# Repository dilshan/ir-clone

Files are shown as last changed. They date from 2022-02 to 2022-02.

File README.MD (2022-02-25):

IR Remote Control Clone Utility
===============================

IR Clone is an open-source infrared remote control signal analysis and generating tool. This utility can clone IR signals, examine the IR remote control signals, and modify or create new IR signals. 

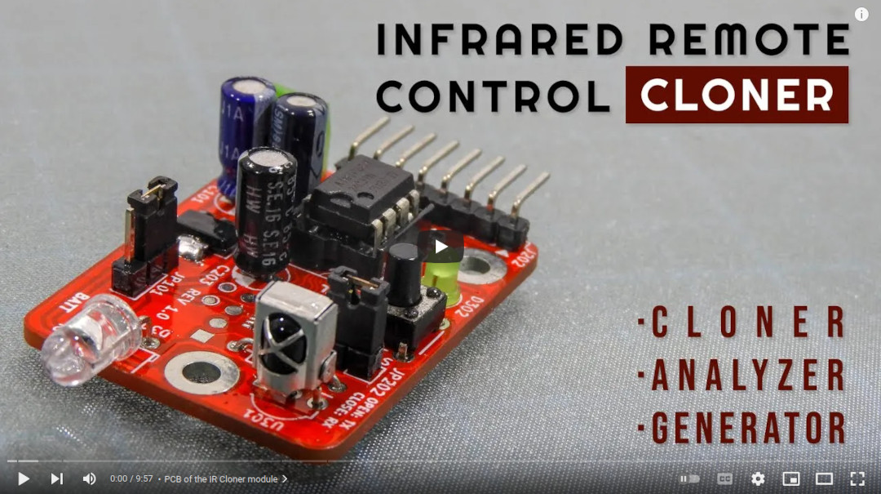
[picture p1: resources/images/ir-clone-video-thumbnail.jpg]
IR Clone build video (https://youtu.be/PBt0_21yzKo)


This project consists of both hardware and software utilities. The hardware module contains an 8-bit MCU, 32Kbit EEPROM, IR receiver, and transmitter.

The software application provides options to decode captured data and generate new IR signals.

IR Clone is an [OSHW certified](https://certification.oshwa.org/lk000011.html) open-source project. All the schematics, PCB design files, firmware source codes, and application source codes are available in this repository.

The complete [documentation](https://github.com/dilshan/ir-clone/wiki) of this project is available in the [wiki](https://github.com/dilshan/ir-clone/wiki) section of this repository. The PCB Gerber files and compiled binaries are also available in the [release](https://github.com/dilshan/ir-clone/releases) section of this repository.

All the content of this project are distributed under the terms of the following license:

- Hardware License: [CERN-OHL-W 2.0](https://ohwr.org/cern_ohl_w_v2.txt)
- Software License: [MIT](https://github.com/dilshan/ir-clone/blob/main/LICENSE)
- [Documentation](https://github.com/dilshan/ir-clone/wiki) License: [CC BY 4.0](https://creativecommons.org/licenses/by/4.0/)

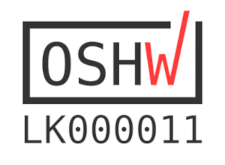
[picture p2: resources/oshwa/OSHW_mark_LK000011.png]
OSHW-LK000011 (https://certification.oshwa.org/lk000011.html)


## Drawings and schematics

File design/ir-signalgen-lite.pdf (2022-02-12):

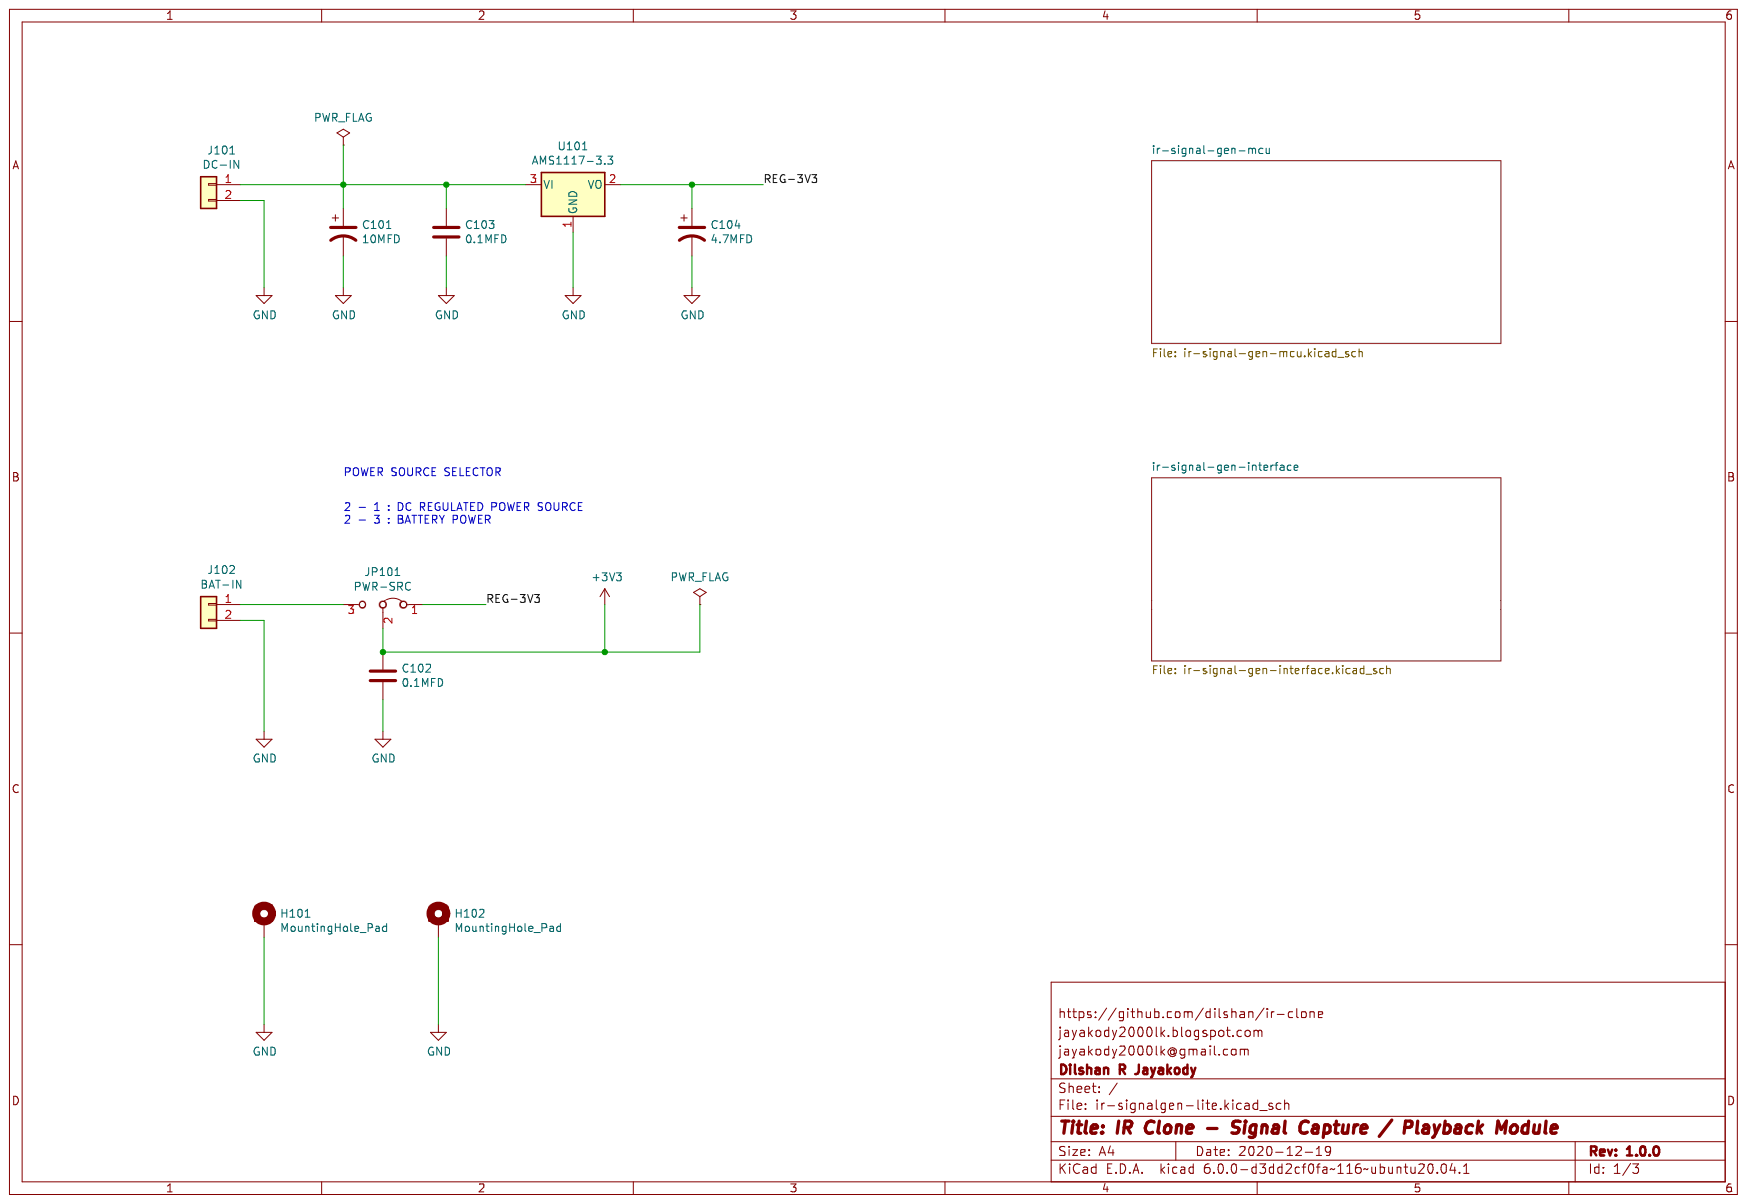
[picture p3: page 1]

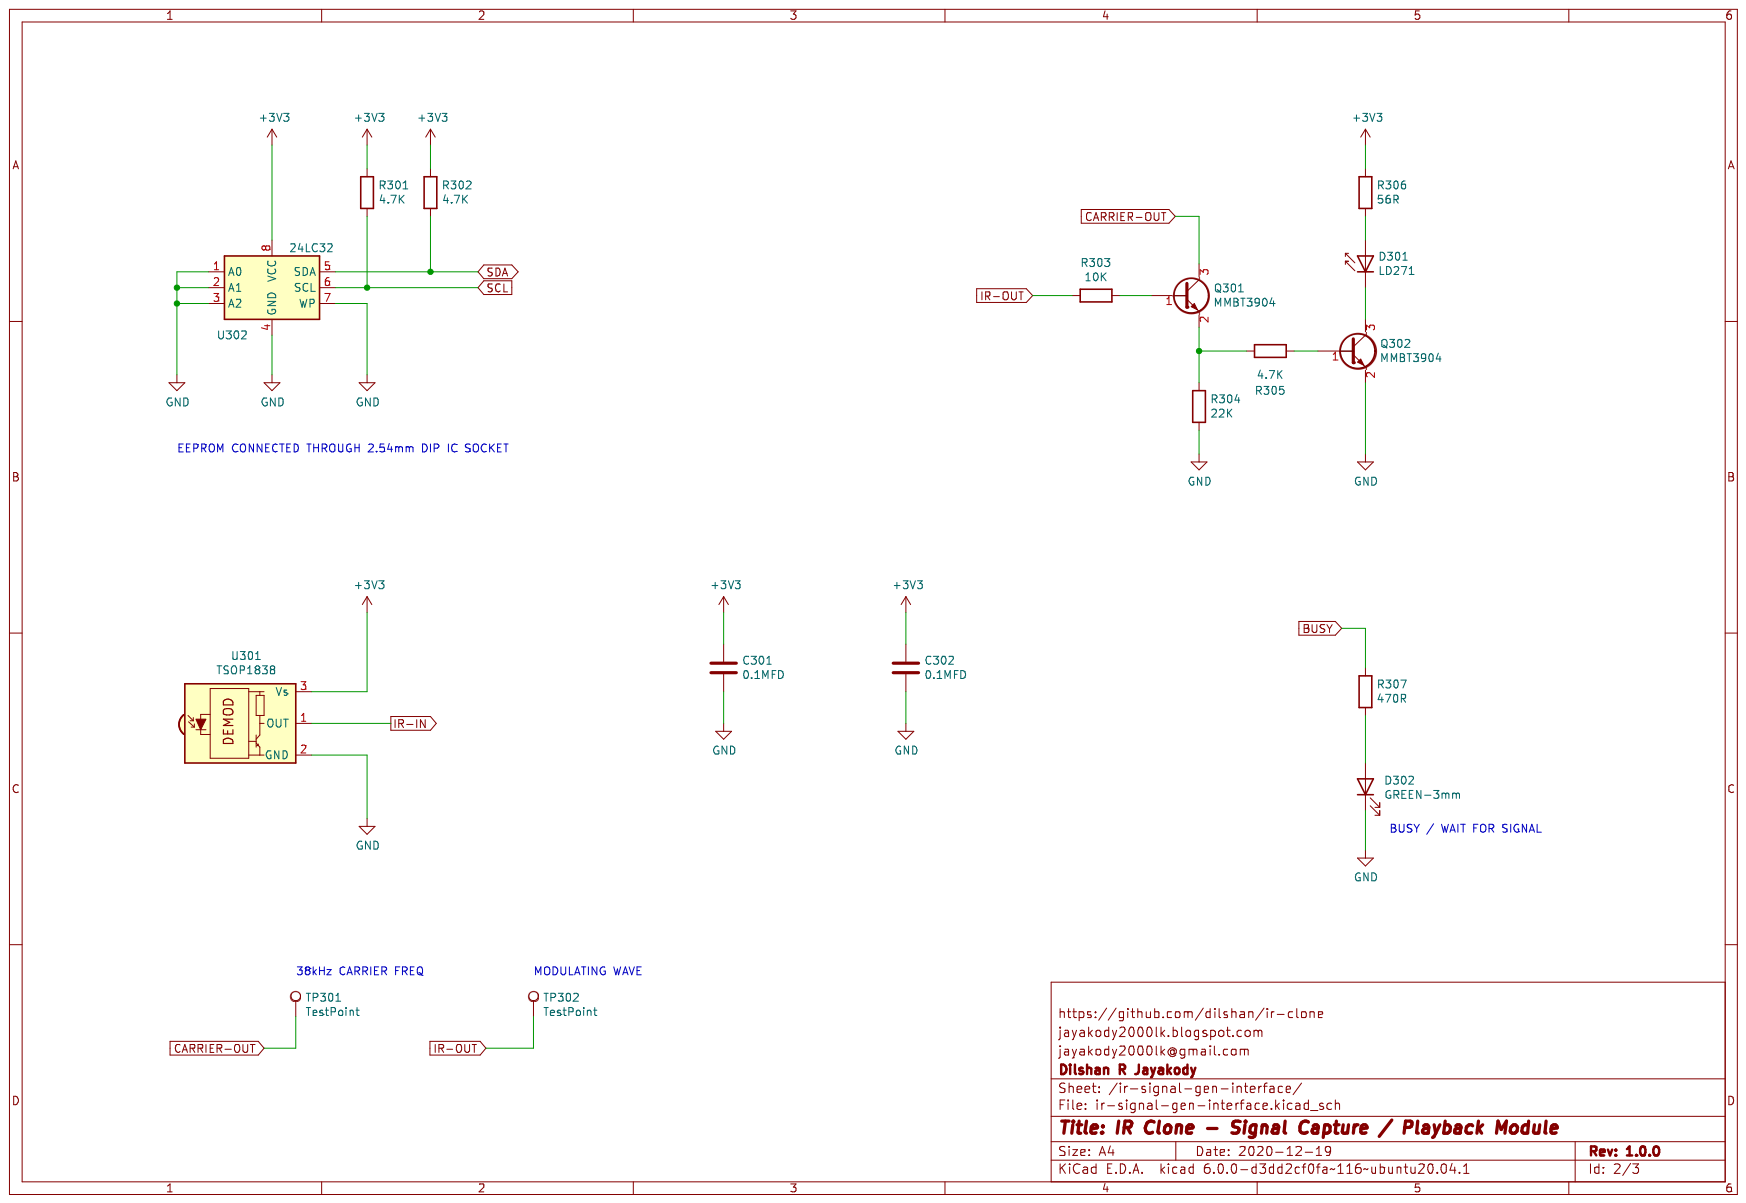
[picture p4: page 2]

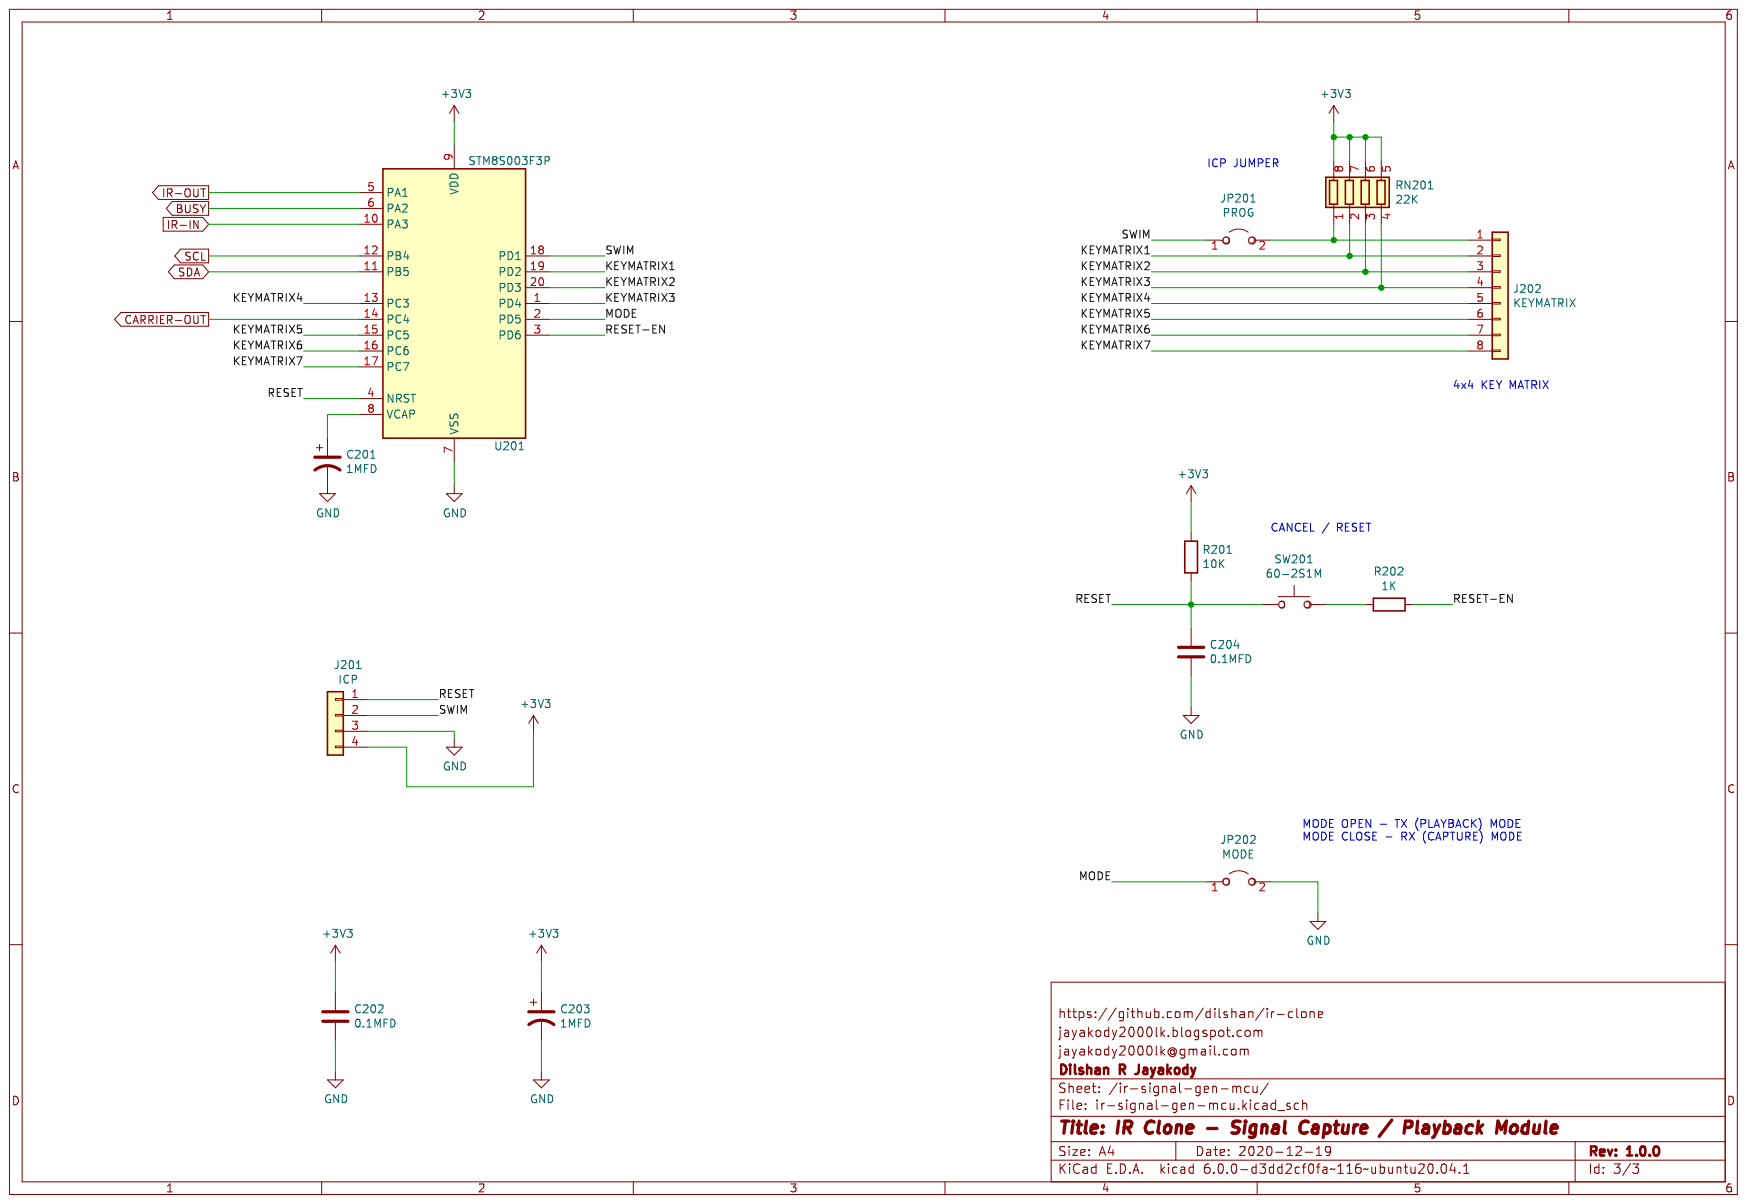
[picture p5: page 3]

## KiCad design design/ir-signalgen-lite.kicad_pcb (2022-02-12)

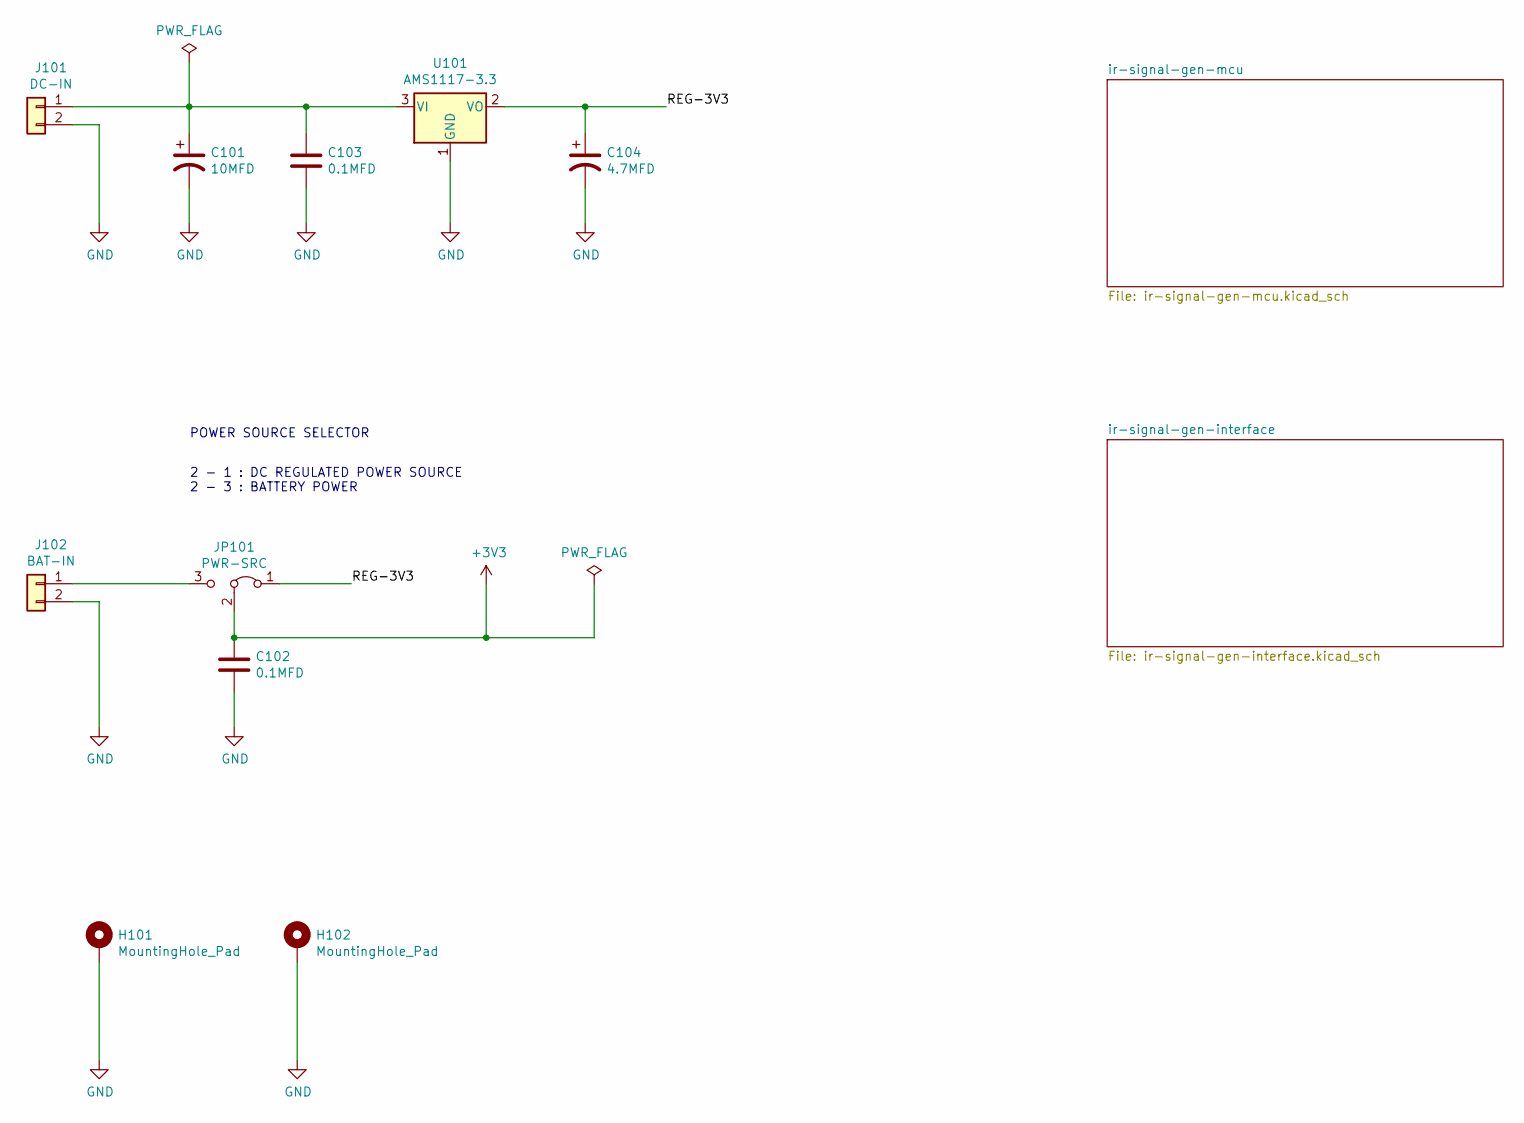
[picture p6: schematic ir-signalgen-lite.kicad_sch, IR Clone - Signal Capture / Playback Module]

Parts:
C101: 10MFD; CP_Radial_D5.0mm_P2.50mm
C102, C103: 0.1MFD; C_0805_2012Metric_Pad1.18x1.45mm_HandSolder
C104: 4.7MFD; CP_Radial_D5.0mm_P2.50mm
H101, H102: MountingHole_Pad; MountingHole_3.2mm_M3_Pad
J101: DC-IN; PhoenixContact_MCV_1,5_2-G-3.5_1x02_P3.50mm_Vertical
J102: BAT-IN; PinHeader_1x02_P2.54mm_Vertical
JP101: PWR-SRC; PinHeader_1x03_P2.54mm_Vertical
U101: AMS1117-3.3; SOT-223-3_TabPin2

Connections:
+3V3: C102.1, JP101.2 (C); also elsewhere on the board
/REG-3V3: C104.1, JP101.1 (A), U101.2 (VO)
GND: C101.2, C102.2, C103.2, C104.2, H101.1, H102.1, J101.2, J102.2, U101.1 (GND); also elsewhere on the board
unnamed: C101.1, C103.1, J101.1, U101.3 (VI)
unnamed: J102.1, JP101.3 (B)

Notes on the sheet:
POWER SOURCE SELECTOR
2 - 1 : DC REGULATED POWER SOURCE 2 - 3 : BATTERY POWER

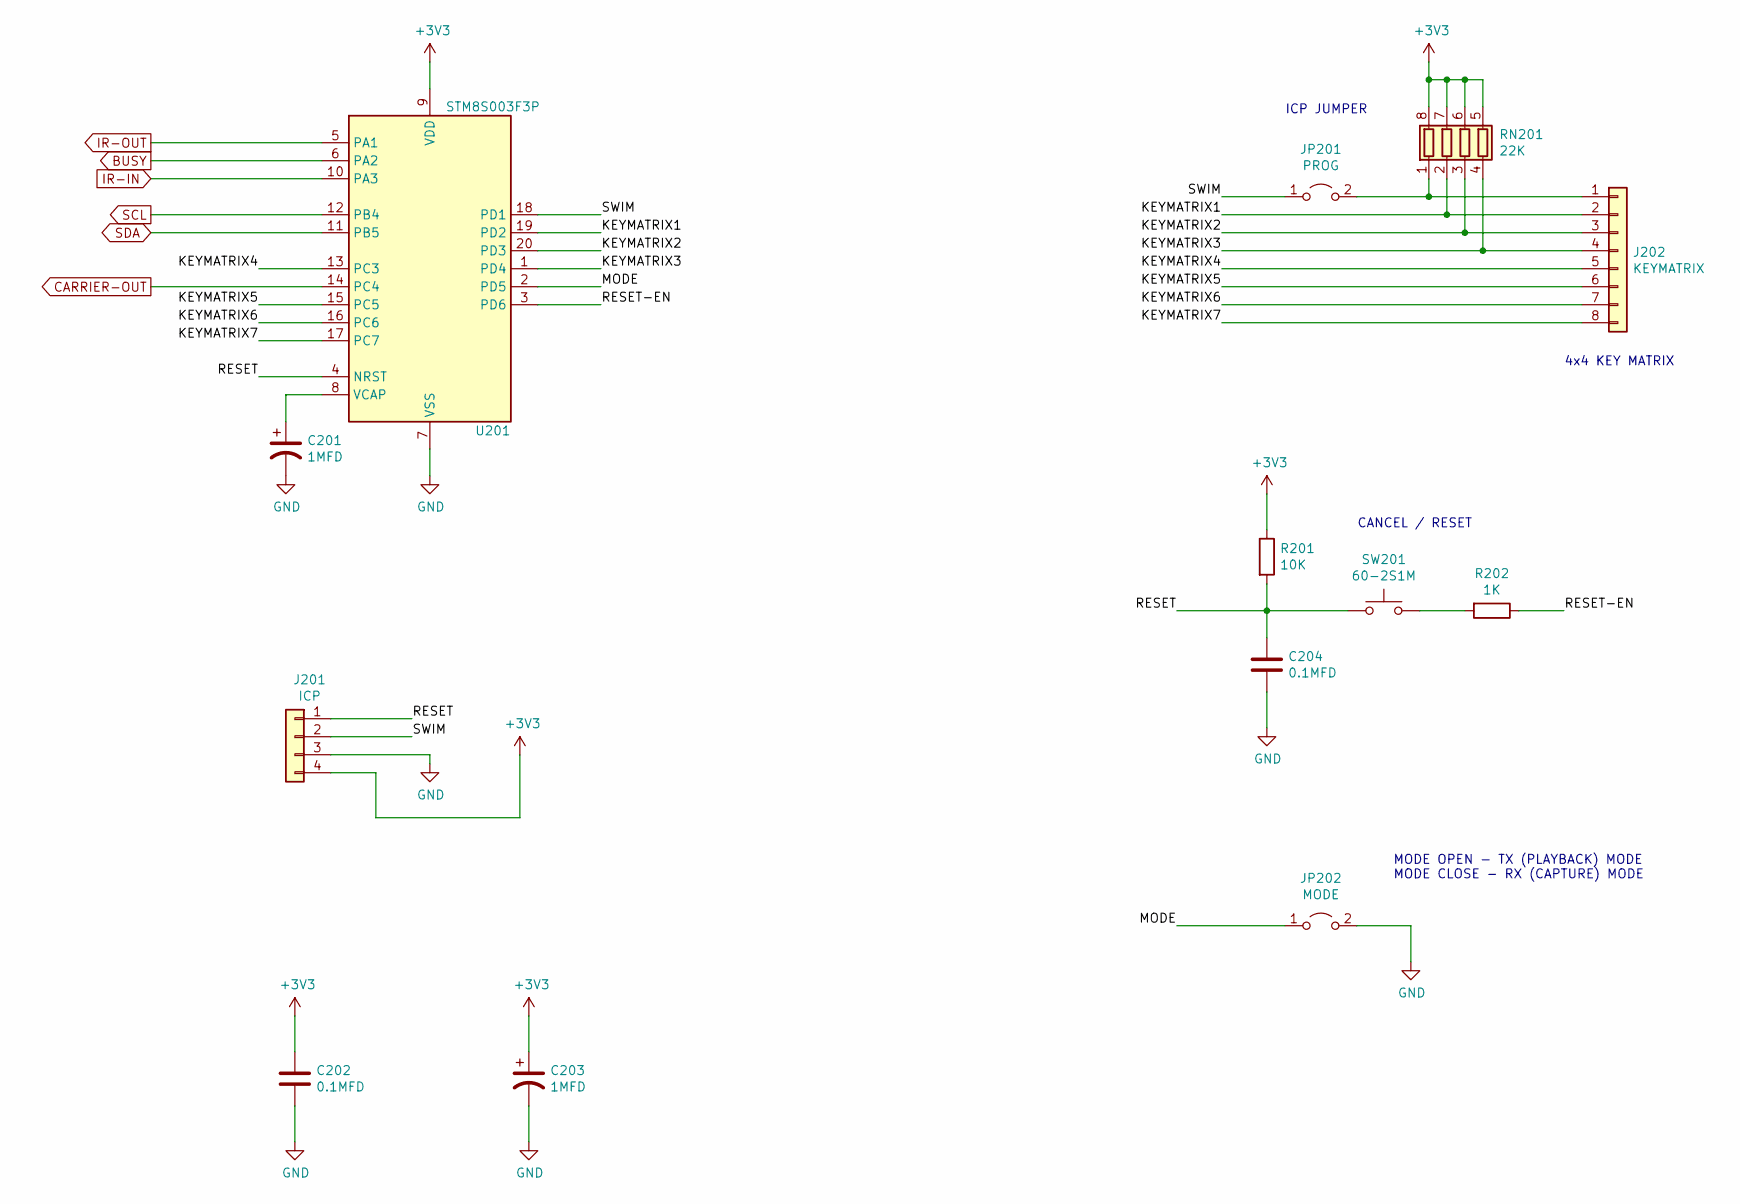
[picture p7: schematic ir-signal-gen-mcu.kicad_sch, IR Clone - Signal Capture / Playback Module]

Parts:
C201: 1MFD; C_0805_2012Metric_Pad1.18x1.45mm_HandSolder
C202, C204: 0.1MFD; C_0805_2012Metric_Pad1.18x1.45mm_HandSolder
C203: 1MFD; CP_Radial_D5.0mm_P2.50mm
J201: ICP; pogo-2.54mmx4
J202: KEYMATRIX; PinHeader_1x08_P2.54mm_Vertical
JP201: PROG; SolderJumper-2_P1.3mm_Bridged_Pad1.0x1.5mm
JP202: MODE; PinHeader_1x02_P2.54mm_Vertical
R201: 10K; R_0805_2012Metric_Pad1.20x1.40mm_HandSolder
R202: 1K; R_0805_2012Metric_Pad1.20x1.40mm_HandSolder
RN201: 22K; R_Array_Convex_4x0603
SW201: 60-2S1M; SW_PUSH_6mm
U201: STM8S003F3P; TSSOP-20_4.4x6.5mm_P0.65mm

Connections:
+3V3: C202.1, C203.1, J201.4, R201.1, RN201.5 (R4.2), RN201.6 (R3.2), RN201.7 (R2.2), RN201.8 (R1.2), U201.9 (VDD); also elsewhere on the board
/ir-signal-gen-mcu/KEYMATRIX1: J202.2, RN201.2 (R2.1), U201.19 (PD2)
/ir-signal-gen-mcu/KEYMATRIX2: J202.3, RN201.3 (R3.1), U201.20 (PD3)
/ir-signal-gen-mcu/KEYMATRIX3: J202.4, RN201.4 (R4.1), U201.1 (PD4)
/ir-signal-gen-mcu/KEYMATRIX4: J202.5, U201.13 (PC3)
/ir-signal-gen-mcu/KEYMATRIX5: J202.6, U201.15 (PC5)
/ir-signal-gen-mcu/KEYMATRIX6: J202.7, U201.16 (PC6)
/ir-signal-gen-mcu/KEYMATRIX7: J202.8, U201.17 (PC7)
/ir-signal-gen-mcu/MODE: JP202.1 (A), U201.2 (PD5)
/ir-signal-gen-mcu/RESET: C204.1, J201.1, R201.2, SW201.1, U201.4 (NRST)
/ir-signal-gen-mcu/RESET-EN: R202.1, U201.3 (PD6)
/ir-signal-gen-mcu/SWIM: J201.2, JP201.1 (A), U201.18 (PD1)
BUSY: U201.6 (PA2); also elsewhere on the board
CARRIER-OUT: U201.14 (PC4); also elsewhere on the board
GND: C201.2, C202.2, C203.2, C204.2, J201.3, JP202.2 (B), U201.7 (VSS); also elsewhere on the board
IR-IN: U201.10 (PA3); also elsewhere on the board
IR-OUT: U201.5 (PA1); also elsewhere on the board
unnamed: C201.1, U201.8 (VCAP)
unnamed: J202.1, JP201.2 (B), RN201.1 (R1.1)
unnamed: R202.2, SW201.2
SCL: U201.12 (PB4); also elsewhere on the board
SDA: U201.11 (PB5); also elsewhere on the board

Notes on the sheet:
ICP JUMPER
CANCEL / RESET
MODE OPEN - TX (PLAYBACK) MODE MODE CLOSE - RX (CAPTURE) MODE
4x4 KEY MATRIX

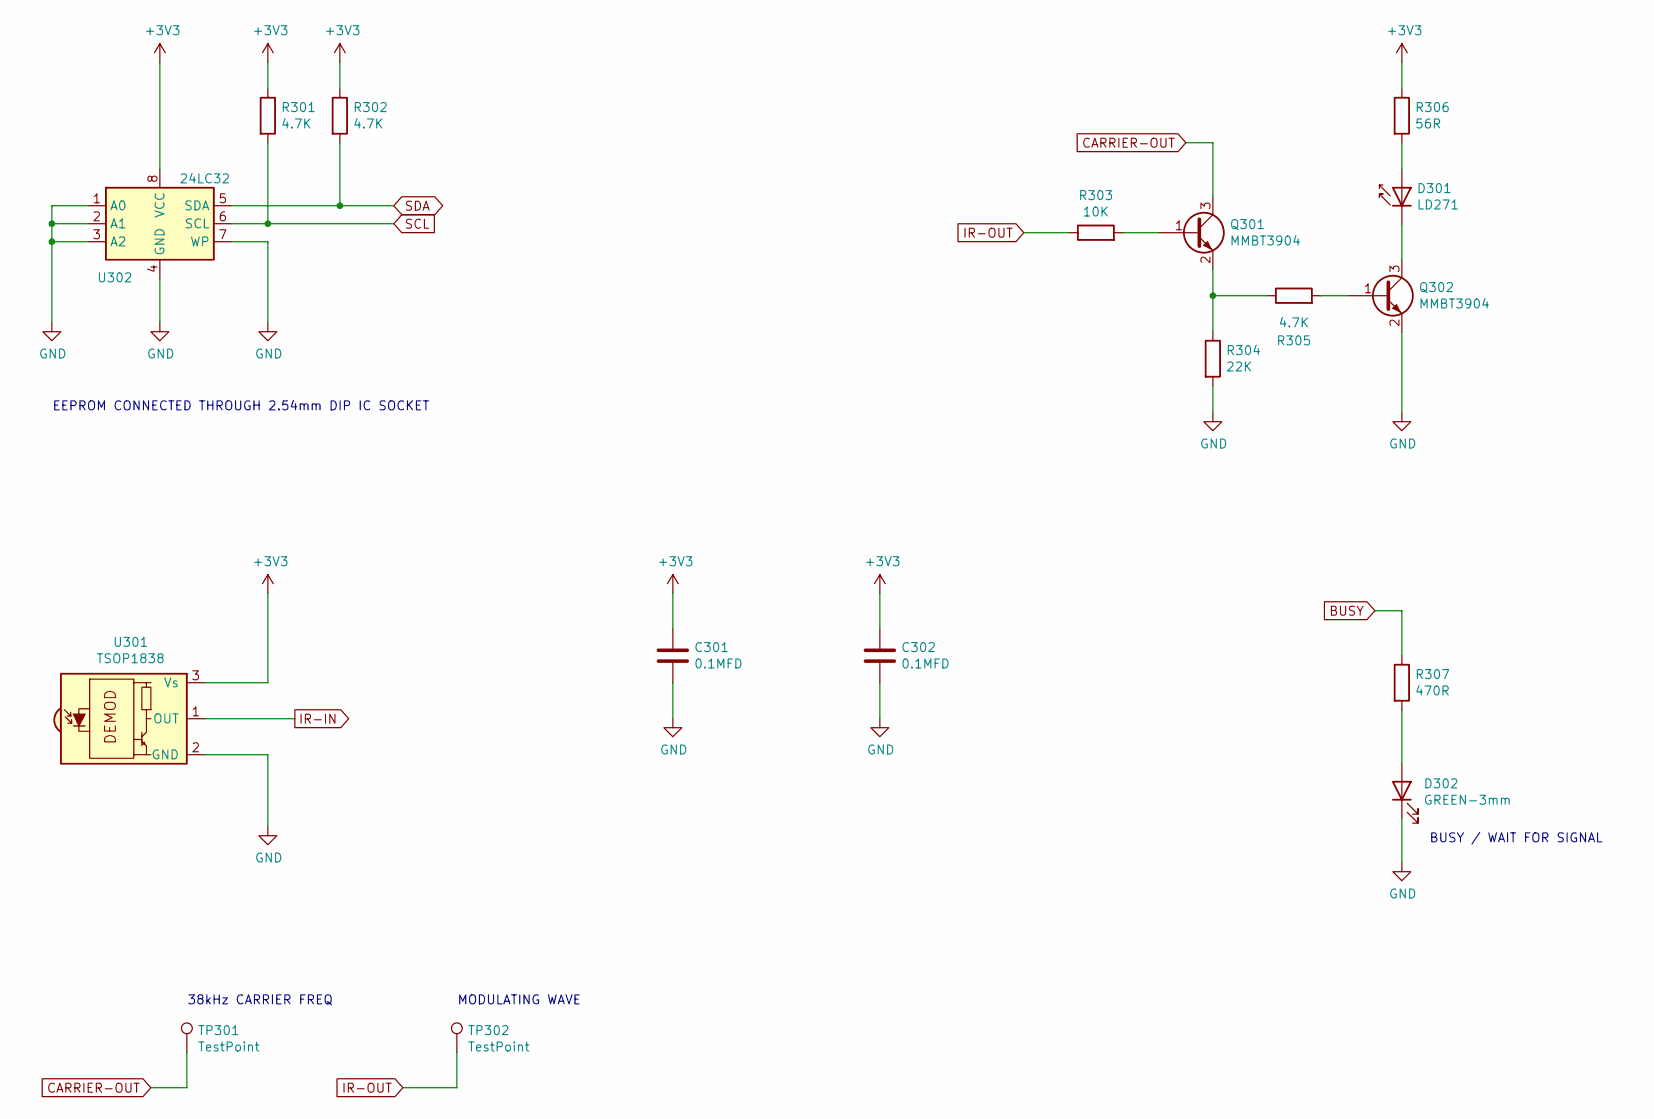
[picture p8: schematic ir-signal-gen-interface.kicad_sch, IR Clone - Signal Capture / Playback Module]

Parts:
C301, C302: 0.1MFD; C_0805_2012Metric_Pad1.18x1.45mm_HandSolder
D301: LD271; LED_D5.0mm_Horizontal_O1.27mm_Z3.0mm
D302: GREEN-3mm; LED_D3.0mm
Q301, Q302: MMBT3904; SOT-23
R301, R302, R305: 4.7K; R_0805_2012Metric_Pad1.20x1.40mm_HandSolder
R303: 10K; R_0805_2012Metric_Pad1.20x1.40mm_HandSolder
R304: 22K; R_0805_2012Metric_Pad1.20x1.40mm_HandSolder
R306: 56R; R_Axial_DIN0207_L6.3mm_D2.5mm_P10.16mm_Horizontal
R307: 470R; R_0805_2012Metric_Pad1.20x1.40mm_HandSolder
TP301, TP302: TestPoint; TestPoint_Pad_D1.0mm
U301: TSOP1838; Vishay_MOLD-3Pin
U302: 24LC32; DIP-8_W7.62mm_Socket_LongPads

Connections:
+3V3: C301.1, C302.1, R301.1, R302.1, R306.1, U301.3 (Vs), U302.8 (VCC); also elsewhere on the board
BUSY: R307.1; also elsewhere on the board
CARRIER-OUT: Q301.3 (C), TP301.1; also elsewhere on the board
GND: C301.2, C302.2, D302.1 (K), Q302.2 (E), R304.2, U301.2 (GND), U302.1 (A0), U302.2 (A1), U302.3 (A2), U302.4 (GND), U302.7 (WP); also elsewhere on the board
IR-IN: U301.1 (OUT); also elsewhere on the board
IR-OUT: R303.1, TP302.1; also elsewhere on the board
unnamed: D301.1 (K), Q302.3 (C)
unnamed: D301.2 (A), R306.2
unnamed: D302.2 (A), R307.2
unnamed: Q301.1 (B), R303.2
unnamed: Q301.2 (E), R304.1, R305.1
unnamed: Q302.1 (B), R305.2
SCL: R301.2, U302.6 (SCL); also elsewhere on the board
SDA: R302.2, U302.5 (SDA); also elsewhere on the board

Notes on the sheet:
MODULATING WAVE
38kHz CARRIER FREQ
BUSY / WAIT FOR SIGNAL
EEPROM CONNECTED THROUGH 2.54mm DIP IC SOCKET

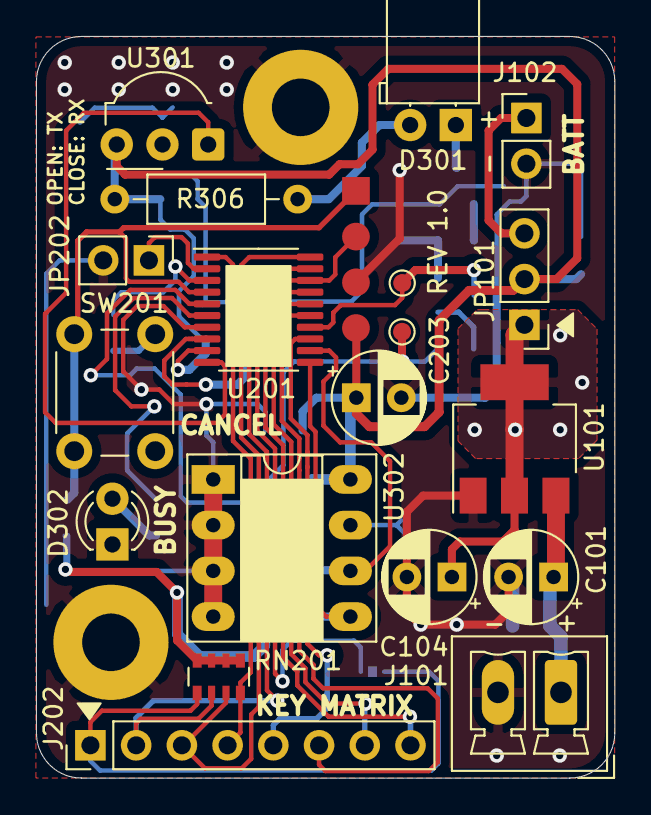
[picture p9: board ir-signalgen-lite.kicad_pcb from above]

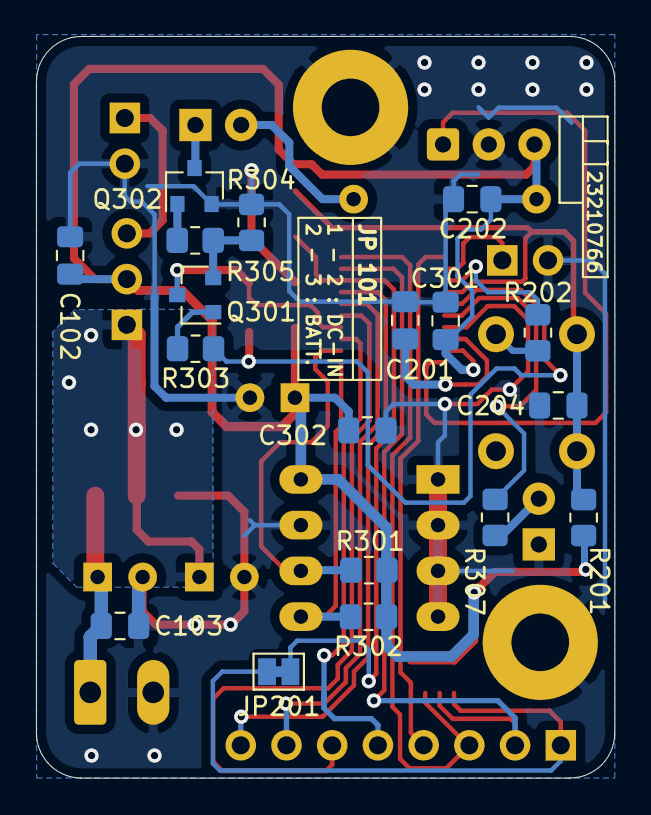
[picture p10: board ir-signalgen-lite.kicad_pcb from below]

Board: 2 copper layers, 32.1 x 41.2 mm, 40 parts (18 on the bottom side), 31 nets.

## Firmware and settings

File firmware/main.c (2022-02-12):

//----------------------------------------------------------------------------------
// IR Remote Cloner firmware for STM8S003F3P6.
// Main source file.
//
// Copyright (c) 2022 Dilshan R Jayakody
//
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
// Last updated: Dilshan Jayakody [11th Dec 2020]
//
// Update log:
// [11/12/2020] - Initial version - Dilshan Jayakody.
//----------------------------------------------------------------------------------

#include "main.h"

#include "include/stm8.h"
#include "include/stm8-util.h"
#include "24c-eeprom.h"

unsigned short captureBuffer[CAPTURE_BUFFER_SIZE];
volatile unsigned short timeCounter;
unsigned char bufferPos, bufferSize;
unsigned char inMemoryBufferID;
unsigned char sleepCounter;

void PortD_Trigger() __interrupt(PORTD_IRQ)
{
    // Device wake-up interrupt.
    sleepCounter = 0;
}

void TIM2_update() __interrupt(TIMER2_TRIGGER_IRQ)
{   
    sleepCounter++;
    
    // Clear timer 2 interrupt flag.
    TIM2_SR1 &= ~TIM2_SR1_UIF;
}

void main()
{
    const unsigned char scanData[4] = {0xE0, 0xC8, 0xA8, 0x68};
    unsigned char scanPos;
    unsigned char scanRow, scanCol;
    
    // Initialize the system registers and peripherals.
    cli(); 
    initSystem();

    initExtEEPROM();

    // Initialize global variables.
    timeCounter = 0;
    scanRow = 0;
    scanCol = 0;
    inMemoryBufferID = 0xFF;
    sleepCounter = 0;

    // Enable interrupts.
    sei();

    // Main service loop.
    while(1)
    {        
        // Check for device wake-up from sleep mode.
        if(PD_CR2 != 0x00)
        {
            // Disable port D interrupts and shutdown Port C pull-down configuration.            
            PD_CR2 = 0x00;
            PC_ODR = 0xE8;
            PD_ODR = 0x40;
        }

        // Check idle timeout to enter device into sleep mode.
        if(sleepCounter > IDLE_TIMEOUT)
        {            
            // Enter device into sleep mode.
            PD_CR2 = 0x1E;
            PD_ODR = 0x00;

            // Set Port C to pull-down configuration to detect user key press (for wake-up).
            PC_ODR &= 0x17;
            sleepCounter = 0;

            halt();
        }
        
        scanPos = 0;
        scanRow = 0;
        scanCol = 0;

        // Start checking key-matrix for any key presses.
        while(scanPos < 4)
        {
            PC_ODR = scanData[scanPos];            
            if((PD_IDR & 0x1E) != 0x1E)
            {
                // Key press found, detect row and column of the pressed-key.
                sleepCounter = 0;
                scanRow = scanPos + 1;
                scanCol = ((~PD_IDR) & 0x1E) >> 1;
                break;
            }
            
            scanPos++;
        }

        // Reset (shutdown) keyboard scanning signals.
        PC_ODR = 0xE8;

        if((scanCol > 0) && (scanRow > 0))
        {
            // Key press is released, execute the action related to the key.
            scanPos = decodeKeyMatrix(&scanRow, &scanCol);

            if(scanPos < 16)
            {                
                // Disable interrupts and enable reset control.
                cli();
                PD_ODR = 0x00;

                // Select capture or transmit based on the mode jumper.
                if((PD_IDR & 0x20))
                {
                    // Transmit mode.
                    startTransmit(scanPos);
                }
                else
                {
                    // Capture mode.                    
                    startCapture(scanPos);
                } 

                // Enable interrupts and disable reset control.
                sleepCounter = 0;

                sei();   
                PD_ODR = 0x40;
            }        
        }

        delay_ms(1);
    }
}

unsigned char decodeKeyMatrix(unsigned char *row, unsigned char *col)
{   
    unsigned char retKey;
    
    // Decode row value.
    switch(*row)
    {
        case 1:
            retKey = 0;
            break;
        case 2:
            retKey = 4;
            break;
        case 3:
            retKey = 8;
            break;
        case 4:
            retKey = 12;
            break;
        default:
            // Unknown row value.
            return 0xFF;
    }

    // Decode column value to get the final key-pressed value.
    switch (*col)
    {
        case 1:
            return retKey + 0;
        case 2:
            return retKey + 1;
        case 4:
            return retKey + 2;
        case 8:
            return retKey + 3;
        default:
            // Unknown column value.
            return 0xFF;
    }
}

void initSystem()
{
    // Switch high speed internal clock prescaler (HSIDIV) to divide by 0 mode (16MHz).
    CLK_ECKR = 0x00;    
    CLK_CKDIVR = 0x00;
    CLK_PCKENR1 = 0xFF;
    CLK_PCKENR2 = 0xFF;
    CLK_CCOR = 0x00;

    // Select high speed internal clock (HSI) as master clock. 
    CLK_SWR = 0xE1;
    
    // Switching to new clock configuration.
    CLK_SWCR = 0x00;
    CLK_SWCR |= 0x02;

    // Waiting for switching to new clock configuration.
    while(CLK_SWCR & 0x01);

    // PA1[OUT] : IR LED drive.
    // PA2[OUT] : Capture / Busy status LED.
    // PA3[IN]  : TSSOP1838 IR photo module input.
    PA_DDR = 0xF7;
    PA_CR1 = 0xFF;
    PA_CR2 = 0x00;
    PA_ODR = 0x00;

    // PD1..PD4 [IN] : Keyboard input.
    // PD5[IN]  : Capture / Transmit mode selector.
    // PD6[OUT] : Reset control pin.
    PD_DDR = 0xC1;
    PD_CR1 = 0x60;
    PD_CR2 = 0x00;
    PD_ODR = 0x40;

    // PC3, PC4..PC7 [OUT] : Keyboard scan data.
    PC_DDR = 0xE8;
    PC_CR1 = 0xE8;
    PC_CR2 = 0x00;
    PC_ODR = 0xE8;

    // Setup Timer 1 to generate 38kHz carrier waveform on TIM1_CH4.
    TIM1_ARRH = 0x00;
    TIM1_ARRL = 0x33;

    TIM1_PSCRH = 0;
    TIM1_PSCRL = 0x07;

    // Enable PWM mode 2 on Timer 1.
    TIM1_CCMR4 |= 0x70;

    // Set PWM output enable on Timer 1 channel 4 (TIM1_CH4).
    TIM1_CCER2 |= 0x10;

    // Based on TIM1_ARR set duty cycle to 50%.
    TIM1_CCR4H = 0x00;
    TIM1_CCR4L = 0x1A;

    // Enable main output.
    TIM1_BKR = 0x80; 

    // Turn off carrier waveform output.
    TIM1_CR1 = 0x00;  

    // Set timer 2 prescaler to 256.
    TIM2_PSCR = 8;

    // Set ARRH to get 1 second interrupt.
    TIM2_ARRH = 0xF4;
    TIM2_ARRL = 0x24; 

    // Enable timer 2 interrupt.
    TIM2_IER |= TIM2_IER_UIE;
    TIM2_CR1 |= TIM2_CR1_CEN;

    // Configure Port D interrupts to trigger on both rising and falling edges. 
    EXTI_CR1 |= 0xC0;
}

void startTransmit(unsigned char buttonID)
{
    unsigned short eepromAddr = buttonID * CAPTURE_BUFFER_SIZE * 2;
    unsigned char tempPos;

    // Activate busy LED.
    PA_ODR |= 0x04;

    // Load button data from the EEPROM, only if it is not available in the memory.
    if(inMemoryBufferID != buttonID)
    {
        // Clear data buffer.
        for(tempPos = 0; tempPos < CAPTURE_BUFFER_SIZE; tempPos++)
        {
            captureBuffer[tempPos] = 0;
        }
        
        // Get the length of the data buffer.
        bufferSize = readExtEEPROM(eepromAddr++);
        bufferPos = 0;
        delay_ms(5);

        // Load IR transmit data into buffer.
        if((bufferSize > 0) && (bufferSize < CAPTURE_BUFFER_SIZE))
        {
            while(bufferPos < bufferSize)
            {
                captureBuffer[bufferPos] = readExtEEPROM(eepromAddr++);
                captureBuffer[bufferPos] = captureBuffer[bufferPos] << 8;
                delay_ms(4);
                captureBuffer[bufferPos] |= readExtEEPROM(eepromAddr++);
                delay_ms(5);

                bufferPos++;
            }
        }
        else
        {
            // Invalid buffer size or corrupted EEPROM data.
            bufferPos = 0;
            PA_ODR &= 0xF9;

            return;
        }
    }

    // Activate carrier wave osciliator.
    TIM1_CR1 = 0x01;
    delay_ms(3);

    // Reset counter and set waveform output to low [0] level.
    bufferPos = 0;
    PA_ODR &= 0xFD;

    while(bufferPos < bufferSize)
    {
        // Get length of the next wavrform.
        timeCounter =  captureBuffer[bufferPos];
        if(timeCounter > 0)
        {
            // Toggle output waveform.
            PA_ODR ^= 0x02;

            // Consume length of the waveform.
            while(timeCounter > 0)
            {
                delay_cycle(TRANSMIT_DELAY);
                timeCounter--;
            }   
        }
        
        // Go to next waveform record.
        bufferPos++;
    }

    // Shutdown waveform output and carrier wave osciliator.
    PA_ODR &= 0xFD;
    TIM1_CR1 = 0x00;

    // Turn off busy indicator.
    PA_ODR &= 0xFB;

    // Set ID belongs to the current memory buffer.
    inMemoryBufferID = buttonID;
}

void startCapture(unsigned char buttonID)
{    
    unsigned char temp, bufPos;
    unsigned short eepromAddr = buttonID * CAPTURE_BUFFER_SIZE * 2;
    
    // Initialize variables used for capturing.
    timeCounter = 0;
    bufferPos = 0;
    inMemoryBufferID = 0xFF;

    // Clear data buffer.
    for(temp = 0; temp < CAPTURE_BUFFER_SIZE; temp++)
    {
        captureBuffer[temp] = 0;
    }

    // Activate capture LED.
    PA_ODR |= 0x04;
    temp = 0x08;

    // Waiting for IR signal to start the capture.
    while(PA_IDR & 0x08)
    {
        nop();
    }

    // Start capture loop.
    do
    {        
        if((PA_IDR & 0x08) ^ temp)
        {
            // Signal state change detected. Capture counter value and reset the counter.
            captureBuffer[bufferPos] = timeCounter;
            bufferPos++;
            timeCounter = 0;
            temp = (PA_IDR & 0x08);
        }
        
        // Wait for 10us delay.
        delay_cycle(CAPTURE_DELAY);
        timeCounter++;
    }
    while((timeCounter <= TIMEOUT_LIMIT) && (bufferPos < CAPTURE_BUFFER_SIZE));

    if(bufferPos > 0)
    {        
        // Write captured data into EEPROM.
        writeExtEEPROM(eepromAddr++, bufferPos);
        delay_ms(5);
        for(bufPos = 0; bufPos < bufferPos; bufPos++)
        {
            // Write captured time limits into the EEPROM.
            writeExtEEPROM(eepromAddr++, ((captureBuffer[bufPos] >> 8) & 0xFF));
            delay_ms(5);
            writeExtEEPROM(eepromAddr++, (captureBuffer[bufPos] & 0xFF));
            delay_ms(5);
        }
    }

    // Turn off capture indicator.
    PA_ODR &= 0xFB;
}

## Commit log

2022-02-12 Add initial version of schematic and PCB design files.
    [ir-signal-gen-interface.kicad_sch, ir-signal-gen-mcu.kicad_sch, ir-signalgen-lite.kicad_pcb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]
2022-02-16 Add Fritzing design files and test setup schematic.
    [ir-clone-test-setup.fzz]
2022-02-16 Update test setup with description.
    [ir-clone-test-setup.fzz]
2022-02-16 Add test setup with 3V battery power.
    [ir-clone-test-setup-battery.fzz]
2022-02-16 Update Fritzing layouts with JP101 positions.
    [ir-clone-test-setup-battery.fzz, ir-clone-test-setup.fzz]
2022-02-16 Add initial version of PCB mounting layout.
2022-02-16 Add YouTube video thumbnail :camera:
